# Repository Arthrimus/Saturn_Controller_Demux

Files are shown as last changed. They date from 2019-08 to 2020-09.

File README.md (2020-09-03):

# Sega Saturn Crontroller Input Demultiplexed to Discrete Outputs.

This is an Arduino sketch for demultiplexing Saturn controller inputs to discrete outputs. I desinged it for Arcade Supergun use but it could be adapted for use in many other control applications that require discrete outputs.

# Instructions

The upload the .ino file to an Arduino Uno or similar compatible device and connect the I/O pins according to the pinout below.

# Pinout (Arduino pin labels) 

  These values are hard coded and cannot be easily changed. This is because the code uses direct port maniplulation to set the button outputs to open drain when not pressed. This is a safety feature.

**Button Outputs**
  - UP    = 1
  - Select = 2
  - DOWN  = 4
  - LEFT  = 5
  - RIGHT = 6
  - X     = 7
  - Y     = 8
  - Z     = 9
  - A     = 10
  - START = 11  
  - B     = 13
  - C     = 12

**Digital Inputs**
- D1    = 14
- D0    = 15
- D3    = 18
- D2    = 19

**Select Outputs**
- S0    = 16
- S1    = 17

# Coin Button

Since the Saturn pad doesn't have a select button I have implemented a software solution for adding coins. Coin can be triggered by pressing any 3 face buttons and Start simultaniously. This combination of buttons will cancel out the Start button press so Coin and Start cannot be triggered simultaniously in this way. There is also support for mapping coin to any of the 6 face buttons or shoulder buttons. When mapped to any of these buttons Coin does not cancel out Start, so they can both be pressed simultaniously. 

# BUTTON REMAPPING AND AUTOFIRE

The now standard firmware supports button remapping and autofire settings for all 6 face buttons and both triggers.

To enter button remapping mode hold any 2 face buttons and START simultaniously for 3 seconds.
Once in remapping mode press each button the corresponding number of times to achive the desired output based on the list below.

 - X = 1 press
 - Y = 2 presses
 - Z = 3 presses
 - A = 4 presses
 - B = 5 presses
 - C = 6 presses
 - Coin = 7 presses
 - N/A = 8 presses

 To enter auto fire programming mode hold any 1 face button and START simultaniously for 3 seconds. 
 Once in auto fire programming mode press each button that you want to set as auto fire the number of times that corresponds to the desired speed in the list below.
 
  - ~30hz = 1 press
  - ~20hz = 2 presses
  - ~15hz = 3 presses
  - ~12hz = 4 presses
  - ~7.5hz = 5 presses
  - ~6hz = 6 presses
  - N/A = 7 presses
  
Button mapping and auto fire settings are saved in the EEPROM so they will persist after power cycling the AVR.

This branch is dependent on the library "DigitalWriteFast" it can be found here. https://github.com/NicksonYap/digitalWriteFast

# Custom PCB Info.

I have designed several prototype PCBs for this project. Currently they are available as Saturn to DB15 adapters. You can find the most up to date version in the root of the PCB folder of this repository.

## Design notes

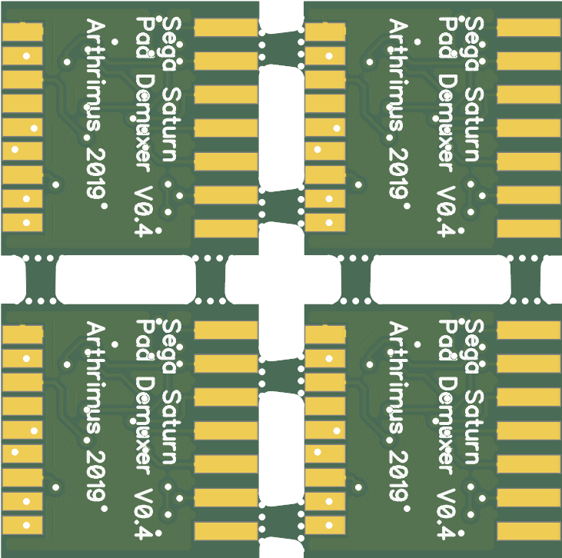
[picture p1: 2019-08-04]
PCB/Gerbers/v0.4 Panelized/saturn_controller_demux_v0.4 4x panel_Combined_Bottom.png

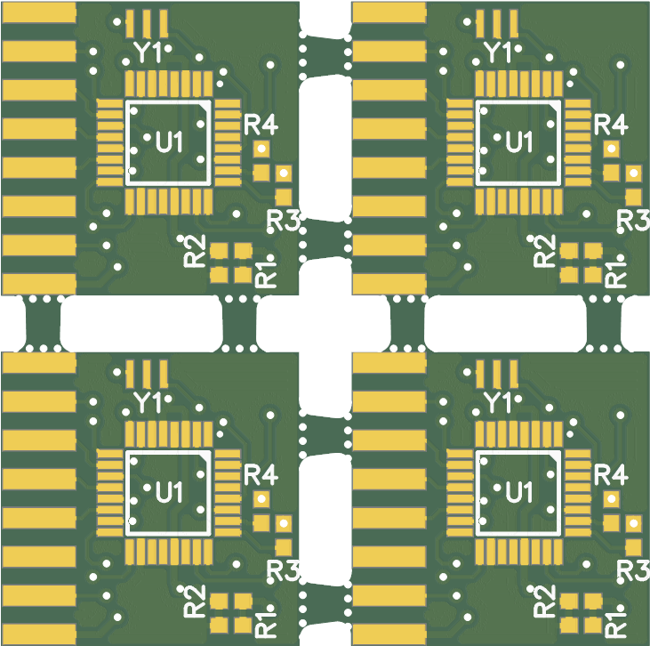
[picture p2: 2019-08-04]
PCB/Gerbers/v0.4 Panelized/saturn_controller_demux_v0.4 4x panel_Combined_Top.png

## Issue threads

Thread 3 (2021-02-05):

Use of the 9th DB15 Pin

guitaristtom, 2021-02-05:
I noticed in the Undamned USB Decoder spec sheet that it _technically_ has pin 9 unused, but I've seen a few posts online of people using that for a D or W button.

https://cdn.shopify.com/s/files/1/0399/1689/6418/files/UD-USB_Decoder_Guide_15PIN_1.0.pdf

I also noticed in the README for this that you had `N/A = 8 presses` in the `BUTTON REMAPPING AND AUTOFIRE` part, is that utilizing the 9th pin on the DB15 port? Or is that just a catch-all for if the user presses the button too many times?

I tried reading through the `.ino` file, but it's a bit above my level for Arduino's C variant.

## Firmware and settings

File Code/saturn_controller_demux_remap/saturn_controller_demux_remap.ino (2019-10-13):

 /* Saturn Controller Demux
 * ------------------ 
 * This sketch is designed to demux Sega Saturn gamepad
 * signals into descrete outputs for use with arcade 
 * PCBs. 
 * 
 * There are two select lines, four data input lines, and
 * 12 discrete outputs.
 * 
 * 
 * Arthrimus October 13th 2019
 *
 */

#include <EEPROM.h>

//Buttonpress Status Variables
int UP = 0;                      // Sets up button press variables.
int DN = 0; 
int LT = 0;
int RT = 0;
int A = 0;
int B = 0;
int C = 0;
int X = 0;
int Y = 0;
int Z = 0;
int L = 0;
int R = 0;
int ST = 0;   
int SL = 0;
// Digital Pins (Arduino)
int D0 = 15;                     // choose the input pins for the digital inputs, follows Arduino pinout.
int D1 = 14;
int D2 = 19;
int D3 = 18;
// Select Pins (Arduino)
int S0 = 16;                     // Chooses the output pins for the select outputs, follows Arduino pinout.
int S1 = 17;  
// General Variables
int val = 0;                     // variable for reading the pin status (should be zero)
int outputb = 0;                 // variable for storing PORTB output values.
int outputd = 0;                 // variable for storing PORTD output values.
int buttonmap = 0;               // variable for storing which buttonmap is used for outputs, 0 = sixbuttonmode.
int remapcount = 0;              // variable for storing the count for the button combo timer
int remapcombo = 0;              // variable for storing the button combo state
int combodelay = 80;             // variable for storing the number of cycles for the combo timer
int combodelay2 = 120;           // variable for storing the number of cycles for combo timer 2
int SLcount = 0;                 // variable for storing the count for the select mode combo timer
int NB = 0;                      // variable for storing the number of face buttons pressed simultaniously.
int SLST = 0;
//Buttonmap Values
int XO = 1;                      // Stores the current output map for each input
int YO = 2;
int ZO = 3;
int AO = 4;
int BO = 5;
int CO = 6;
// Previous Buttonpress Variables
int XP = 0;                     // Stores the previous state of each button
int YP = 0;
int ZP = 0;
int AP = 0;
int BP = 0;
int CP = 0;
int LP = 0;
int RP = 0;
// Current Buttonpress Variables
int XC = 0;                    // Stores the current state of each button
int YC = 0;
int ZC = 0;
int AC = 0;
int BC = 0;
int CC = 0;
int STP = 0;

void setup() {
  pinMode(D0, INPUT_PULLUP);     // Declares D0-3 as inputs with internal pullup.
  pinMode(D1, INPUT_PULLUP);
  pinMode(D2, INPUT_PULLUP);
  pinMode(D3, INPUT_PULLUP);
  pinMode(S0, OUTPUT);           // Declares Select Pins as outputs.
  pinMode(S1, OUTPUT);
 
XO = EEPROM.read(0);
YO = EEPROM.read(1);
ZO = EEPROM.read(2);
AO = EEPROM.read(3);
BO = EEPROM.read(4);
CO = EEPROM.read(5);
SLST = EEPROM.read(6);
}


void loop(){                     // The main loop of the program. Calls all of the other loops as needed.
  
  demuxpad();                    // Runs the pad demux operation to collect buttonpress data from the controller

  buttoncombos();                // Runs the button combination check.  
if (buttonmap == 1){             // Stores output data for PORTB and PORTD based on sixbutton map.
  buttonmapping();
}else{
  setoutputs();
  }
  DDRB = outputb;                // Sets PORTB and PORTD outputs based on inputs and the chosen buttonmap.
  DDRD = outputd;
}


void setoutputs(){           // Translates demuxpad data into the sixbutton output map.

if (Y == 2 || X == 2 || Z == 2 || A == 2 || B == 2 || C == 2) 
  outputb |= 1;                    
if (Z == 3 || Y == 3 || X == 3 || A == 3 || B == 3 || C == 3)
  outputb |= 2; 
if (A == 4 || Y == 4 || X == 4 || Z == 4 || B == 4 || C == 4)
  outputb |= 4;    
if (ST == 1) 
  outputb |= 8;
if (C == 6 || Y == 6 || X == 6 || Z == 6 || A == 6 || B == 6)
  outputb |= 16;
if (B == 5 || Y == 5 || X == 5 || Z == 5 || A == 5 || C == 5) 
  outputb |= 32;    
if (UP == 1)
  outputd |= 2;                    
if (SL == 1)
  outputd |= 4;
if (DN == 1)
  outputd |= 16;           
if (LT == 1)   
  outputd |= 32;
if (RT == 1)
  outputd |= 64;
if (X == 1 || Y == 1 || Z == 1 || A == 1 || B == 1 || C == 1) 
  outputd |= 128;    
}




void demuxpad(){               // Does the heavy lifting of demuxing the data from the controller into buttonpresses.

// New Previous State 
XP = XC;                      // new previous state variables = old current state variables
YP = YC;
ZP = ZC;
AP = AC;
BP = BC;
CP = CC;
LP = L;
RP = R;
STP = ST;
// Reset All Variables
outputb = 0;                   // Resets Port Maniplulation Variables
outputd = 0;
UP = 0;                        // Resets all button state variables
DN = 0;
LT = 0;
RT = 0;
SL = 0;
ST = 0;
NB = 0;
XC = 0;
YC = 0;
ZC = 0;
AC = 0;
BC = 0;
CC = 0;
X = 0;
Y = 0;
Z = 0;
A = 0;
B = 0;
C = 0;

  {                             // This is the start of the first bit of the demuxer, there are four of these
  delay(1);
  digitalWrite(S1, LOW);
  digitalWrite(S0, HIGH);       // Sets the select lines S0 HIGH, S1 LOW
  
  }
  val = digitalRead(D0);        // read input value from data line
  if (val == LOW) {             // check if the data input is LOW (button pressed)
  B = BO;                        // Stores the B button as pressed.
  BC = 1;                     
  }
  val = digitalRead(D1); 
  if (val == LOW) {       
  C = CO;
  CC = 1;
  }
  val = digitalRead(D2);
  if (val == LOW) {       
  A = AO;
  AC = 1;
  }
  val = digitalRead(D3); 
  if (val == LOW) {      
  ST = 1;
  }                              // This is the end of the first bit of the demuxer.

{                                // This is the start of the second bit of the demuxer.
  delay(1);
  digitalWrite(S1, LOW);         // Sets the select lines S0 LOW, S1 LOW
  digitalWrite(S0, LOW);         
  }
    val = digitalRead(D0);
  if (val == LOW) {       
  Z = ZO;
  ZC = 1;
  }
  val = digitalRead(D1); 
  if (val == LOW) {      
  Y = YO;
  YC = 1;
  }
  val = digitalRead(D2);
  if (val == LOW) {       
  X = XO;
  XC = 1;
  }
  val = digitalRead(D3); 
  if (val == LOW) {           
  R = 1;  
  }else{R = 0;
  }                             // This is the end of the second bit of the demuxer.       
          { 
  delay(1);                     // This is the start of the third bit of the demuxer.
  digitalWrite(S1, HIGH);       // Sets the select lines S0 HIGH, S1 HIGH
  digitalWrite(S0, HIGH);  

  }
  val = digitalRead(D3); 
  if (val == LOW) {      
  L = 1;                     
  }  else{L = 0;
  }                          // This is the end of the third bit of the demuxer. 
   {                           // This is the start of the fourth bit of the demuxer.
  delay(17);
  digitalWrite(S1, HIGH);      // Sets the select lines S0 LOW, S1 HIGH
  digitalWrite(S0, LOW);   

  }
    val = digitalRead(D0); 
  if (val == LOW) {       
  UP = 1;
  }
  val = digitalRead(D1); 
  if (val == LOW) {      
  DN = 1;
  }
  val = digitalRead(D2);
  if (val == LOW) {       
  LT = 1;
  }
  val = digitalRead(D3); 
  if (val == LOW) {      
  RT = 1;
  }                             // This is the end of the fourth bit of the demuxer. 

NB = (XC + YC + ZC + AC + BC + CC);

} 

void buttoncombos(){
if (ST == 1){
  SLcount = 0;  
}
if ((NB == 3 && (ST == 1)) || (L == 1 && (ST == 1 && (R == 1 && SLST == 0))) || (L == 1 && SLST == 1) || (R == 1 && SLST == 2)){       // Checks if X,Y,Z and Start or L, R and Start are all pressed
  SL = 1;                       // Sets Select as pressed
  ST = 0;                       // Sets Start as pressed
}
if (L == 1 && (R == 1 && (LP == 1 && (RP == 1)))){        // Checks if Start and 2 buttons are pressed. 
  SLcount = (SLcount + 1);
}else{ 
  SLcount = 0;
}

if (SLcount >= combodelay2){{
SLcount = 0;
SLST = (SLST + 1);                
 }
if (SLST > 2){
  SLST = 0;
}
EEPROM.write(6,SLST);
}

if (ST == 1 && (NB == 2 && (STP == 1))){        // Checks if Start and 2 buttons are pressed. 
  remapcount = (remapcount + 1);
}else{ 
  remapcount = 0;
}

if (remapcount >= combodelay){
remapcount = 0;
buttonmap = 1;                // Sets buttonmap mode to 1 
 }
}

void buttonmapping(){
if (ST == 1 && (NB == 2)){                        // Checks if the buttonmap combo is still held. 
 XO = 0;                                          // Resets all buttonmap values to 0
 YO = 0;
 ZO = 0;
 AO = 0;
 BO = 0;
 CO = 0;
}else{                                                       // If buttonmap combo is no longer pressed, continue to button mapping mode
if (XC == 1 && (XP == 0 && (NB == 1))){            // If X is currently pressed, if X was previously not pressed, if only one button (X) is pressed and if XO is less than 6
  XO = (XO + 1);                                             // If all of the above conditions are met, XO is iterated +1
}
if (XO > 6){                                       // If XO is greater than 6, XO is reset to 0
  XO = 0;
}
if (YC == 1 && (YP == 0 && (NB == 1))){
  YO = (YO + 1);
}
if (YO > 6){
  YO = 0;
}
if (ZC == 1 && (ZP == 0 && (NB == 1))){
  ZO = (ZO + 1);
}
if (ZO > 6){
  ZO = 0;
}
if (AC == 1 && (AP == 0 && (NB == 1))){
  AO = (AO + 1);
}
if (AO > 6){
  AO = 0;
}
if (BC == 1 && (BP == 0 && (NB == 1))){
  BO = (BO + 1);
}
if (BO > 6){
  BO = 0;
}
if (CC == 1 && (CP == 0 && (NB == 1))){
  CO = (CO + 1);
}
if (CO > 6){
  CO = 0;
  }
if (ST == 1 && (STP == 0)){
    buttonmap = 0;
    EEPROM.write(0,XO);
    EEPROM.write(1,YO);
    EEPROM.write(2,ZO);
    EEPROM.write(3,AO);
    EEPROM.write(4,BO);
    EEPROM.write(5,CO);
    
  } 
 }
}

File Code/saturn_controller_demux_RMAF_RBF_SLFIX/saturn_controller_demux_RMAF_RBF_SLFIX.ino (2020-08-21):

#include <digitalWriteFast.h>

 /* Saturn Controller Demux
 * ------------------ 
 * This sketch is designed to demux Sega Saturn gamepad
 * signals into descrete outputs for use with arcade 
 * PCBs. 
 * 
 * There are two select lines, four data input lines, and
 * 12 discrete outputs.
 * 
 * 
 * Arthrimus October 13th 2019
 *
 */

#include <EEPROM.h>

//Buttonpress Status Variables
int UP = 0;                      // Sets up button press variables.
int DN = 0; 
int LT = 0;
int RT = 0;
int A = 0;
int B = 0;
int C = 0;
int X = 0;
int Y = 0;
int Z = 0;
int L = 0;
int R = 0;
int ST = 0;   
int SL = 0;
// Digital Pins (Arduino)
const int D0 = 15;                     // choose the input pins for the digital inputs, follows Arduino pinout.
const int D1 = 14;
const int D2 = 19;
const int D3 = 18;
// Select Pins (Arduino)
const int S0 = 16;                     // Chooses the output pins for the select outputs, follows Arduino pinout.
const int S1 = 17;  
// General Variables
int val0 = 0;                     // variable for reading the pin status (should be zero)
int val1 = 0;
int val2 = 0;
int val3 = 0;
int outputb = 0;                 // variable for storing PORTB output values.
int outputd = 0;                 // variable for storing PORTD output values.
int buttonmap = 0;               // variable for storing which buttonmap is used for outputs, 0 = sixbuttonmode.
int remapcount = 0;              // variable for storing the count for the button combo timer
int remapcombo = 0;              // variable for storing the button combo state
int autofire = 0;
int autofirecombo = 0;
int autofirecount = 0;
int autofiretimer1 = 0;
int autofiretimer2 = 0;
int autofiretimer3 = 0;
int autofiretimer4 = 0;
int autofiretimer5 = 0;
int autofiretimer6 = 0;
int combodelay = 160;             // variable for storing the number of cycles for the combo timer
int combodelay2 = 220;           // variable for storing the number of cycles for combo timer 2
int SLcount = 0;                 // variable for storing the count for the select mode combo timer
int NB = 0;                      // variable for storing the number of face buttons pressed simultaniously.
int NB2 = 0;
int SLST = 0;
int cdetect = 0;
int HASmode = 0;
int HAScount = 0;
//Buttonmap Values
int XO = 1;                      // Stores the current output map for each input
int YO = 2;
int ZO = 3;
int AO = 4;
int BO = 5;
int CO = 6;
int LO = 7;
int RO = 7;
//Autofire Values
int XA = 0;                      // Stores the current autofire setting for each input
int YA = 0;
int ZA = 0;
int AA = 0;
int BA = 0;
int CA = 0;
int LA = 0;
int RA = 0;
// Previous Buttonpress Variables
int XP = 0;                     // Stores the previous state of each button
int YP = 0;
int ZP = 0;
int AP = 0;
int BP = 0;
int CP = 0;
int LP = 0;
int RP = 0;
// Current Buttonpress Variables
int XC = 0;                    // Stores the current state of each button
int YC = 0;
int ZC = 0;
int AC = 0;
int BC = 0;
int CC = 0;
int LC = 0;
int RC = 0;
int STP = 0;

void setup() {
  pinModeFast(D0, INPUT_PULLUP);     // Declares D0-3 as inputs with internal pullup.
  pinModeFast(D1, INPUT_PULLUP);
  pinModeFast(D2, INPUT_PULLUP);
  pinModeFast(D3, INPUT_PULLUP);
  pinModeFast(S0, OUTPUT);           // Declares Select Pins as outputs.
  pinModeFast(S1, OUTPUT);

HASmode = EEPROM.read(17);
if (HASmode != 0 && HASmode != 1){
  HASmode = 0;
  EEPROM.write(17,HASmode);
}
 
  if (HASmode == 0){
    for (int i = 0; i <= 11; i++) {
    DDRD = 0;
    delay(16);
    DDRD |= 1;
    delay(16);
  }
XO = EEPROM.read(0);
YO = EEPROM.read(1);
ZO = EEPROM.read(2);
AO = EEPROM.read(3);
BO = EEPROM.read(4);
CO = EEPROM.read(5);
LO = EEPROM.read(13);
RO = EEPROM.read(14);
SLST = EEPROM.read(6);
XA = EEPROM.read(7);
YA = EEPROM.read(8);
ZA = EEPROM.read(9);
AA = EEPROM.read(10);
BA = EEPROM.read(11);
CA = EEPROM.read(12);
LA = EEPROM.read(15);
RA = EEPROM.read(16);
  }

if (HASmode == 1){
   DDRD |= 1;
   delay(1000);
   DDRD = 0;
}
 DDRC = 0b00001100;
}

void loop(){                     // The main loop of the program. Calls all of the other loops as needed.
 if (cdetect == 0){
  detectpad ();
 }
 if (cdetect == 1){
  demuxpad();                    // Runs the pad demux operation to collect buttonpress data from the controller
   buttoncombos();               // Runs the button combination check.  
if (buttonmap == 1){             // Stores output data for PORTB and PORTD based on sixbutton map.
  autofire = 0;
  buttonmapping();
}else if (autofire == 1){
  autofiremapping();
}else{
  setautofire();
  setoutputs();
  }
 }
  DDRB = outputb;                // Sets PORTB and PORTD outputs based on inputs and the chosen buttonmap.
  DDRD = outputd;
}

void setautofire(){
autofiretimer1 = (autofiretimer1 + 1);
autofiretimer2 = (autofiretimer2 + 1);
autofiretimer3 = (autofiretimer3 + 1);
autofiretimer4 = (autofiretimer4 + 1);
autofiretimer5 = (autofiretimer5 + 1);
autofiretimer6 = (autofiretimer6 + 1);

if (autofiretimer1 > 1){
  autofiretimer1 = 0; 
}
if (autofiretimer2 > 2){
  autofiretimer2 = 0; 
}
if (autofiretimer3 > 3){
  autofiretimer3 = 0; 
}
if (autofiretimer4 > 5){
  autofiretimer4 = 0; 
}
if (autofiretimer5 > 7){
  autofiretimer5 = 0; 
}
if (autofiretimer6 > 9){
  autofiretimer6 = 0; 
}

if ((XA == 1 && autofiretimer1 < 1) || (XA == 2 && autofiretimer2 < 2) || (XA == 3 && autofiretimer3 < 2) || (XA == 4 && autofiretimer4 < 3) || (XA == 5 && autofiretimer5 < 4) || (XA == 6 && autofiretimer6 < 5)){
    X = 0;     
  }
if ((YA == 1 && autofiretimer1 < 1) || (YA == 2 && autofiretimer2 < 2) || (YA == 3 && autofiretimer3 < 2) || (YA == 4 && autofiretimer4 < 3) || (YA == 5 && autofiretimer5 < 4) || (YA == 6 && autofiretimer6 < 5)){
    Y = 0;     
  }
if ((ZA == 1 && autofiretimer1 < 1) || (ZA == 2 && autofiretimer2 < 2) || (ZA == 3 && autofiretimer3 < 2) || (ZA == 4 && autofiretimer4 < 3) || (ZA == 5 && autofiretimer5 < 4) || (ZA == 6 && autofiretimer6 < 5)){
    Z = 0;     
  }  
if ((AA == 1 && autofiretimer1 < 1) || (AA == 2 && autofiretimer2 < 2) || (AA == 3 && autofiretimer3 < 2) || (AA == 4 && autofiretimer4 < 3) || (AA == 5 && autofiretimer5 < 4) || (AA == 6 && autofiretimer6 < 5)){
    A = 0;     
  }
if ((BA == 1 && autofiretimer1 < 1) || (BA == 2 && autofiretimer2 < 2) || (BA == 3 && autofiretimer3 < 2) || (BA == 4 && autofiretimer4 < 3) || (BA == 5 && autofiretimer5 < 4) || (BA == 6 && autofiretimer6 < 5)){
    B = 0;     
  }
if ((CA == 1 && autofiretimer1 < 1) || (CA == 2 && autofiretimer2 < 2) || (CA == 3 && autofiretimer3 < 2) || (CA == 4 && autofiretimer4 < 3) || (CA == 5 && autofiretimer5 < 4) || (CA == 6 && autofiretimer6 < 5)){
    C = 0;     
  }
if ((LA == 1 && autofiretimer1 < 1) || (LA == 2 && autofiretimer2 < 2) || (LA == 3 && autofiretimer3 < 2) || (LA == 4 && autofiretimer4 < 3) || (LA == 5 && autofiretimer5 < 4) || (LA == 6 && autofiretimer6 < 5)){
    L = 0;     
  }
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

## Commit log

2019-01-13 Added PCB Files
    [saturn_controller_demux_v0.4.brd]
2019-01-13 Revert "Added PCB Files"
    This reverts commit 5717008fefaffe79b07796de60e8ba5abf1f790b.
    [saturn_controller_demux_v0.4.brd]
2019-01-13 Revert "Revert "Added PCB Files""
    This reverts commit a7ca34b18491ff5fecc07db30968687de8d8c1e1.
    [saturn_controller_demux_v0.4.brd]
2019-01-14 Updated PCB files
2019-01-14 Updated code to correct some button mapping issues with thw v0.1 pcb
    [saturn_controller_demux_v0.1_board.ino]
2019-06-09 Added updated code for the V0.6 and newer board revisions
    Added updated code for the V0.6 and newer board revisions. This code fully conforms the pinouts to the newer board designs (v0.5-v0.6) This will also remain the correct code for any newer revisions of the PCB.
    [saturn_controller_demux_v0.6__board.ino]
2019-06-12 Updated PCB Link
2019-08-04 Updated Firmware
    [BoardOutline.gbr, Bottom.gbl, Bottom.gbr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]
2019-08-11 Repository Cleanup
    [BoardOutline.gbr, Bottom.gbl, Bottom.gbr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]
2019-10-05 Added v0.9 firmware.
    V0.9 firmware adds ABC/XYZ flipped mode for buttonmapping. Switching buttonmaps now requires holding the button combos for 3 seconds instead of just pressing.
    [saturn_controller_demux_v0.9.ino]
2019-10-06 Added EEPROM Buttonmap Saving
2019-10-13 Major overhaul of file structure
    [BoardOutline.gbr, Bottom.gbl, BottomMask.gbs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]
2020-01-20 Fixed Controller Detection Routine
    [saturn_controller_demux_RMAF_Retro_Bit_Fix.ino]
2020-08-21 Major code and file structure update
    Moved all but the new and most up to date firmware to the "Old Versions" Folder. The newest firmware now had added support for disabling button remapping and auto fire otherwise known as HAS mode. Al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
